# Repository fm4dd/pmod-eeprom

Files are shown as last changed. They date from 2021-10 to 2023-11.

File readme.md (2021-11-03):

## PMOD-EEPROM



### Description

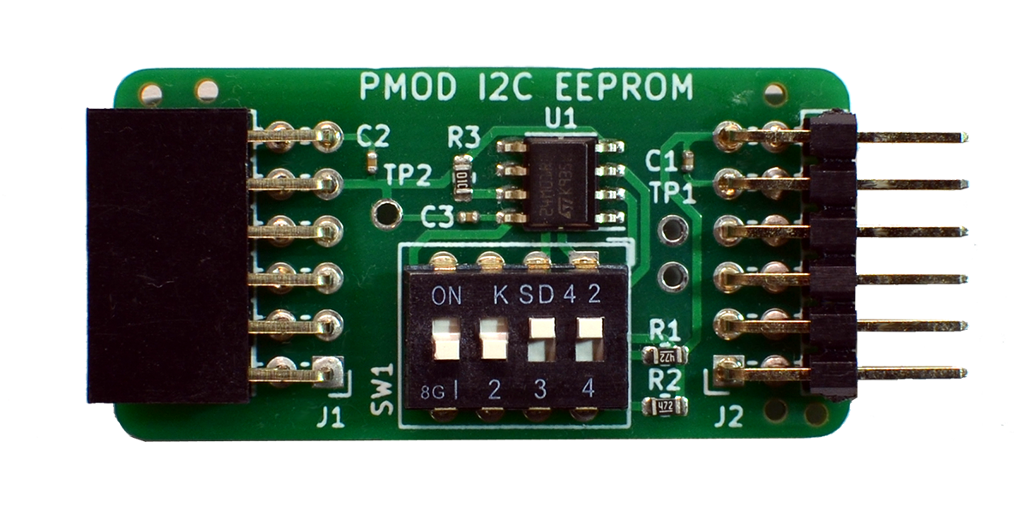
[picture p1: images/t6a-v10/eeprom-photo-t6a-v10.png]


This I2C PMOD provides a 1 Mbit serial EEPROM, using the M24M01 circuit by STMicroelectronics. DIP switches enable I2C pull-up resistors if needed, and change the EEPROM's I2C device address. Up to four modules can be chained for a total capacity of 4 Mbit (512 KBytes). Three Testpoints can be fitted for I2C bus troubleshooting. The PMOD has designs for Type-6 (I2C single row), and for the new Type-6A (I2C extended double row). The picture shows the Type-6A variant (engineering sample).

http://fpga.fm4dd.com/

### Schematic
This is the schema for the PMOD I2C Type-6 (single row) connector variant:
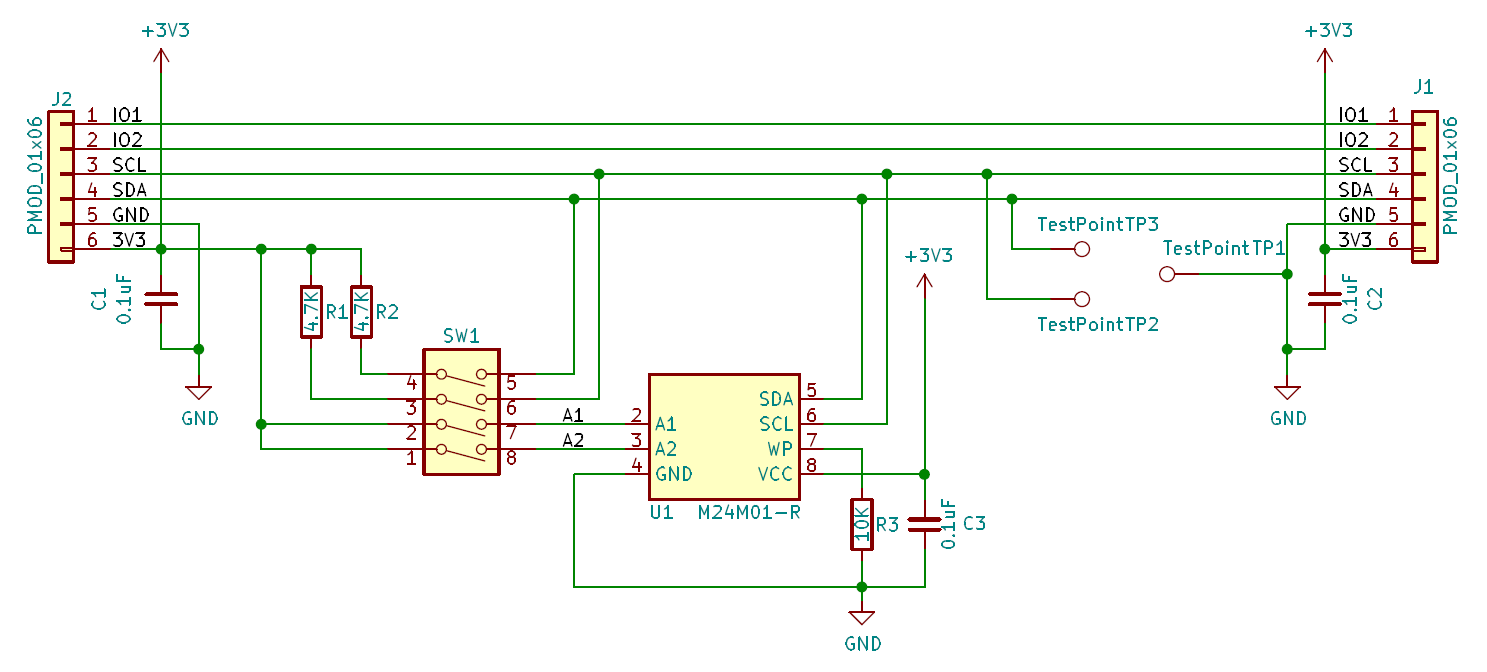
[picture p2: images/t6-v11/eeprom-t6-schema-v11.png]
EEPROM PMOD Schematics


The current EEPROM desin is pulling the "write-protect" pin high for "read-write" operation. A design update may implement a solder pad for setting the EEPROM 'read-only' after programming.

### Hardware Release

|Type | Version | Gerber | Schema |
|---|---|---|---|
|Type-6 |1.1 |[EEPROM PMOD Type-6 Gerber V1.1](release/t6-v11/20210917-eeprom-t6-gerber-v11.zip) | [20210917-eeprom-t6-schema-v11.pdf](release/t6-v11/20210917-eeprom-t6-schema-v11.pdf)
|Type-6A  |1.1 |[EEPROM PMOD Type-6A Gerber V1.1](release/t6a-v11/20210814-eeprom-t6a-gerber-v11.zip) | [20210814-eeprom-t6a-schema-v11.pdff](release/t6a-v11/20210814-eeprom-t6a-schema-v11.pdf)

#### Rasperry Pi I2C Discovery

Ensure the I2C bus is enabled, and install prerequisite I2C tools:
```
# sudo apt-get install git i2c-tools
# raspi-config  2 Interface Options  enable I2C
```

Check the IO expander circuit is visible on the I2C bus under address 0x50..0x56, depending on the address set through the DIP switch. Below example address 0x50/51 is set with SW1-1 = off and SW1-2 = off.
```
pi@pi-ms05:~ $ i2cdetect -y 1
     0  1  2  3  4  5  6  7  8  9  a  b  c  d  e  f
00:          -- -- -- -- -- -- -- -- -- -- -- -- --
10: -- -- -- -- -- -- -- -- -- -- -- -- -- -- -- --
20: -- -- -- -- -- -- -- -- -- -- -- -- -- -- -- --
30: -- -- -- -- -- -- -- -- -- -- -- -- -- -- -- --
40: -- -- -- -- -- -- -- -- -- -- -- -- -- -- -- --
50: 50 51 -- -- -- -- -- -- -- -- -- -- -- -- -- --
60: -- -- -- -- -- -- -- -- -- -- -- -- -- -- -- --
70: -- -- -- -- -- -- -- --
```

### Example code

pmod-eeprom code examples for Arduino boards are available in the [example folder](examples/)

On the Raspberry Pi, the PMOD can be easily programmed with the eeprom utility program 'eepflash.sh'. This program writes a manually created byte file (.eep) as content into the I2C eeprom. It can be found as part of the Raspberry Pi foundation 'hats' repository:
```
pi@pi-ms05:~ $ git clone https://github.com/raspberrypi/hats.git
Cloning into 'hats'...
remote: Enumerating objects: 565, done.
remote: Counting objects: 100% (95/95), done.
remote: Compressing objects: 100% (61/61), done.
remote: Total 565 (delta 59), reused 46 (delta 34), pack-reused 470
Receiving objects: 100% (565/565), 306.34 KiB | 936.00 KiB/s, done.
Resolving deltas: 100% (325/325), done.
```

Compile the tools located in the eepromutils subdirectory:
```
pi@pi-ms05:~ $ cd hats/eepromutils/
pi@pi-ms05:~/hats/eepromutils $ make clean; make
rm -f eepmake eepdump
cc -Wall -Wextra eepmake.c -o eepmake
cc -Wall -Wextra eepdump.c -o eepdump
```
Check the tools:
```
pi@pi-ms05:~/hats/eepromutils $ ls -l
total 84
-rwxr-xr-x 1 pi pi 12820 Aug 28 22:38 eepdump
-rw-r--r-- 1 pi pi  8112 Aug 28 22:37 eepdump.c
-rwxr-xr-x 1 pi pi  3906 Aug 28 22:37 eepflash.sh
-rwxr-xr-x 1 pi pi 22232 Aug 28 22:38 eepmake
-rw-r--r-- 1 pi pi 15144 Aug 28 22:37 eepmake.c
-rwxr-xr-x 1 pi pi  3122 Aug 28 22:37 eeprom_settings.txt
-rw-r--r-- 1 pi pi  2395 Aug 28 22:37 eeptypes.h
-rw-r--r-- 1 pi pi   677 Aug 28 22:37 Makefile
-rw-r--r-- 1 pi pi  1836 Aug 28 22:37 README.md
```

Example upload of an .eep file:
```
pi@pi-ms05:~/hats/eepromutils $ sudo ./eepflash.sh -w -f=rpi2pmod.eep -t=24c32 -d=1 -a=50
This will attempt to talk to an eeprom at i2c address 0x50 on bus 1. Make sure there is an eeprom at this address.
This script comes with ABSOLUTELY no warranty. Continue only if you know what you are doing.
Do you wish to continue? (yes/no): yes
Writing...
0+1 records in
0+1 records out
113 bytes copied, 0.728222 s, 0.2 kB/s
Closing EEPROM Device.
Done.
```

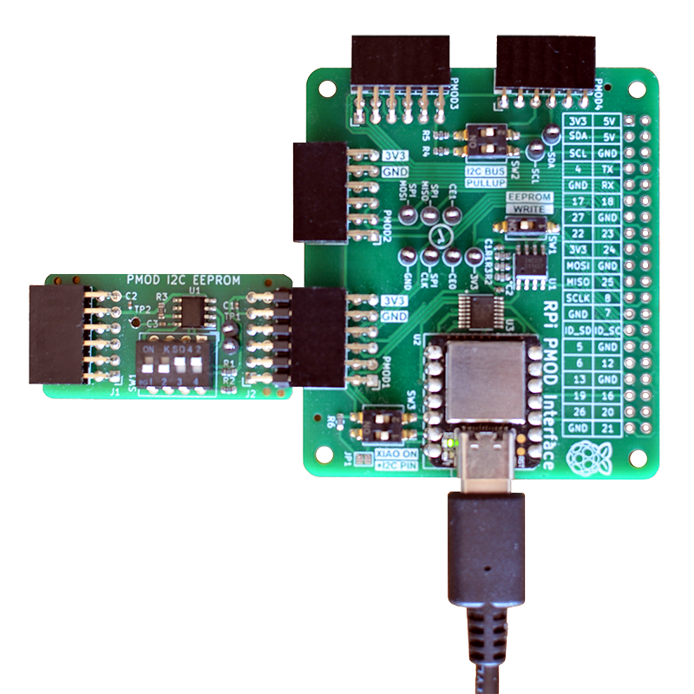
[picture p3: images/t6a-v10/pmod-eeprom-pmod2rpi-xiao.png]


PMOD-EEPROM on a PMOD2RPI interface board, running code from the XIAO Cortex M0+ MCU.

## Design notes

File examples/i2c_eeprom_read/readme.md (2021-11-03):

## i2c_eeprom_read

Arduino Sketch for designs based on the I2C EEPROM PMOD using the M24M01 circuit by STMicroelectronics. Implemented and tested on a PMOD2RPI interface board with a Seeeduino XIAO (Cortex M0+) and a PMOD-EEPROM module. 

### Usage

Running the sketch will output the following to the serial monitor:

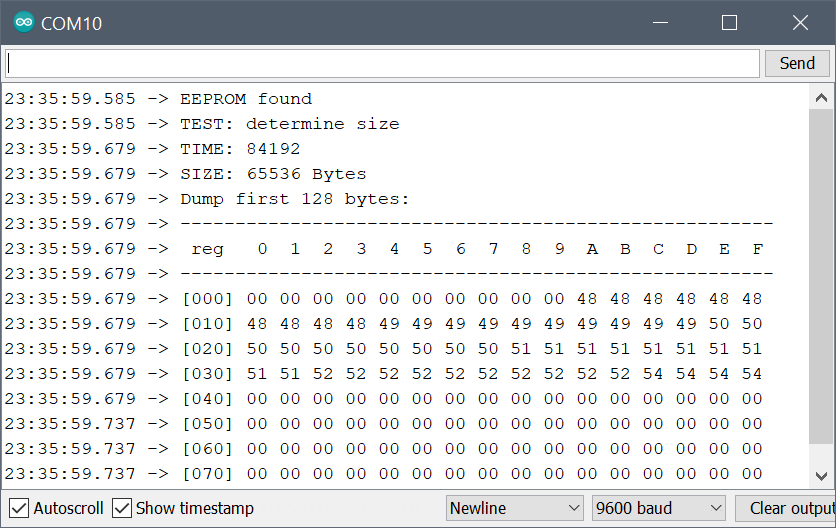
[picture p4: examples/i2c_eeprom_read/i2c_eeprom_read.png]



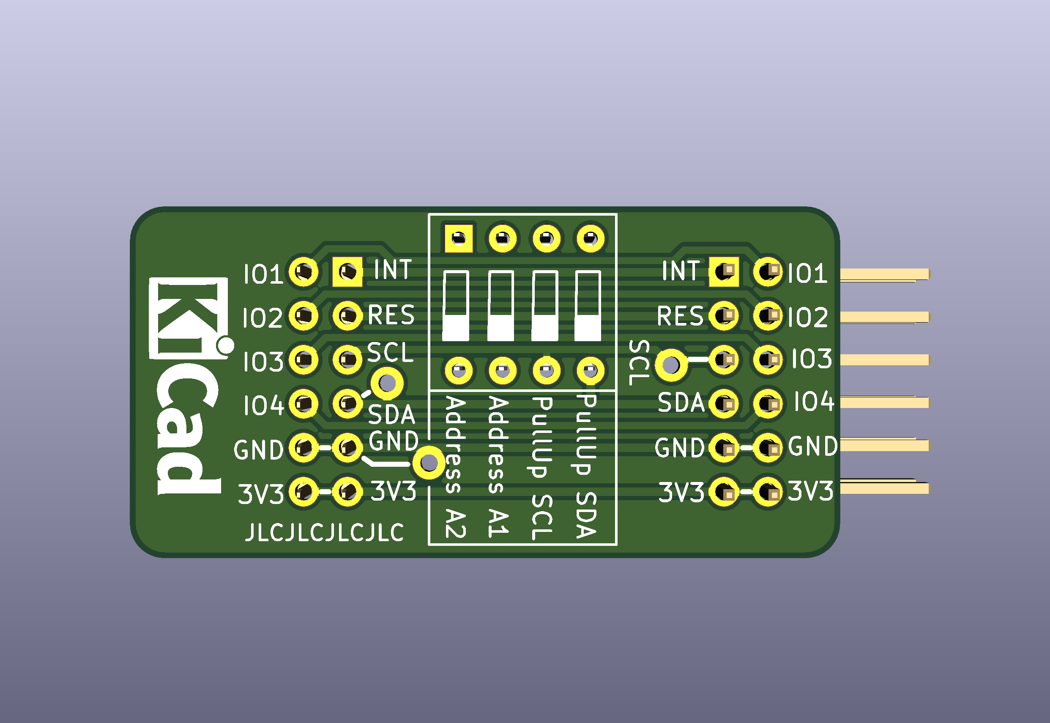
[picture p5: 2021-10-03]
images/t6a-v11/eeprom-bottom-t6a-v11.png

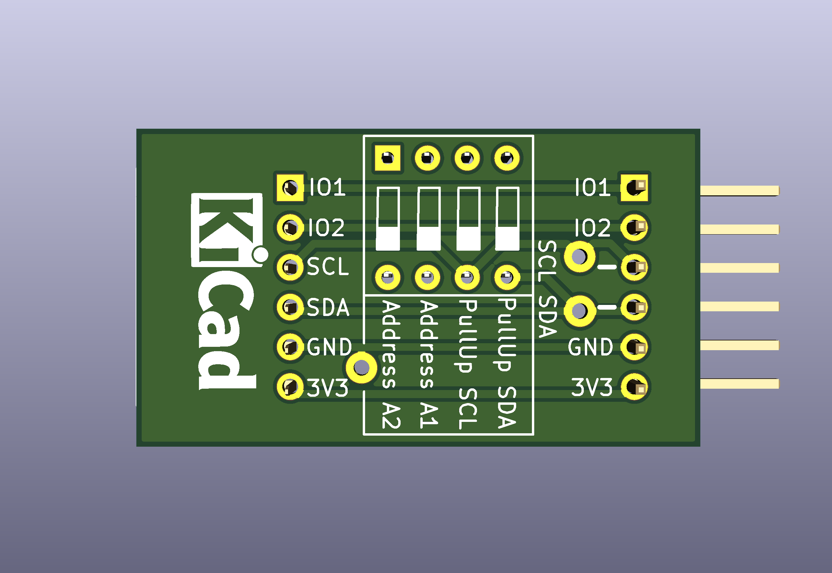
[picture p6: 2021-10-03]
images/t6-v11/eeprom-bottom-t6-v11.png

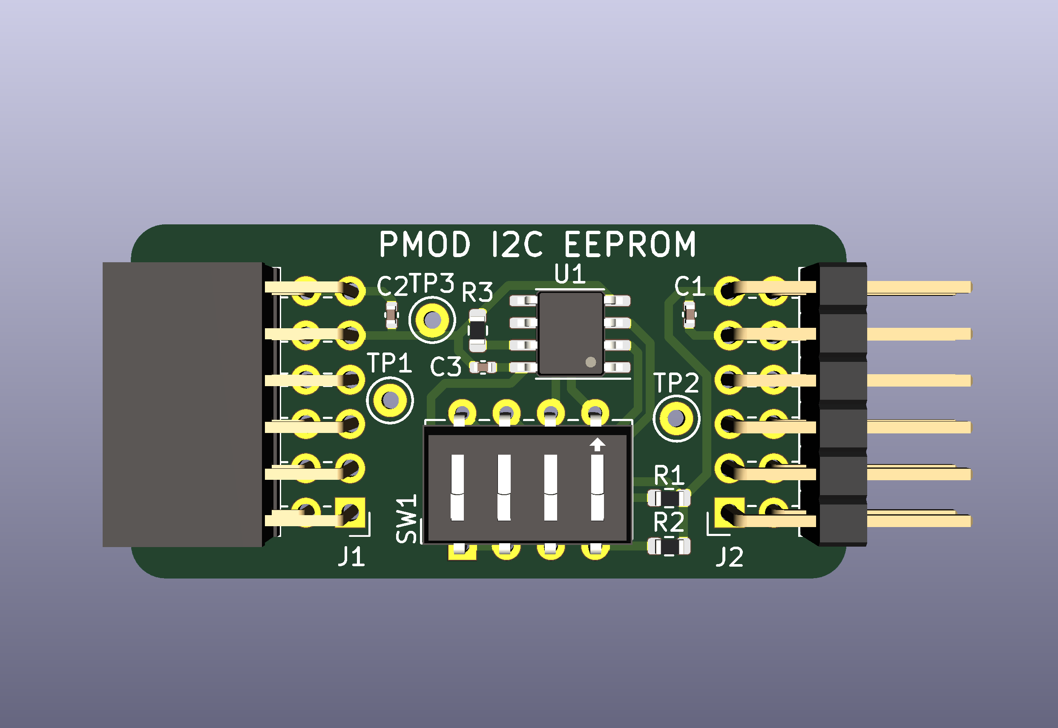
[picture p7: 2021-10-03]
images/t6a-v11/eeprom-top-t6a-v11.png

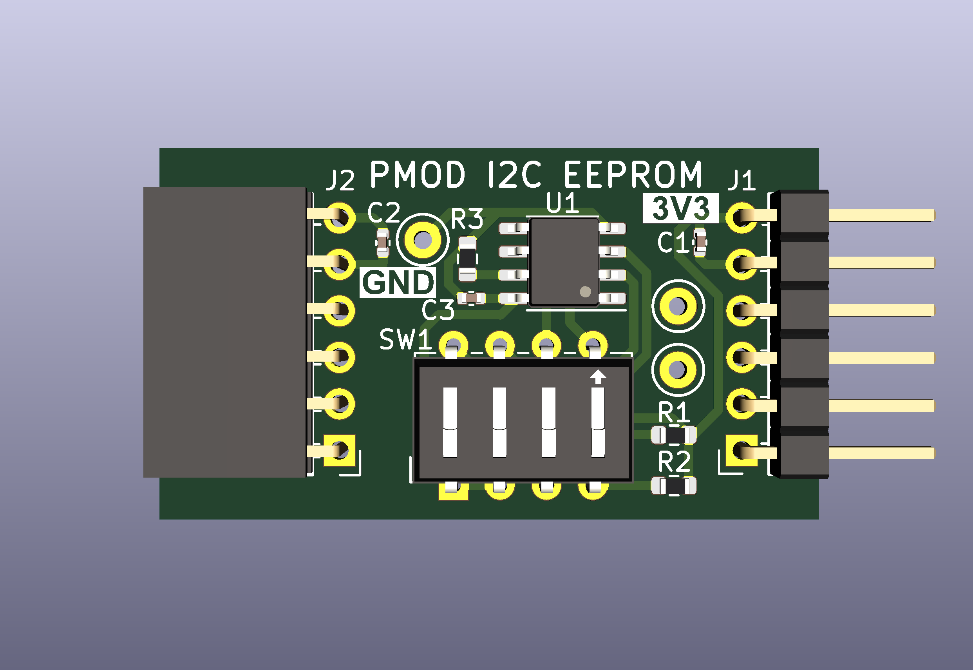
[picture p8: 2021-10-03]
images/t6-v11/eeprom-top-t6-v11.png

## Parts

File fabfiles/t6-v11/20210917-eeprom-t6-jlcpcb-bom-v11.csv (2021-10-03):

Comment | Designator | Footprint | LCSC Part #
M24M01-R | U1 | SOIC-8_3.9x4.9mm_P1.27mm
10K | R3 | Resistor_SMD:R_0603_1608Metric
4.7K | R2,R1 | Resistor_SMD:R_0603_1608Metric
0.1uF | C3,C2,C1 | Capacitor_SMD:C_0603_1608Metric

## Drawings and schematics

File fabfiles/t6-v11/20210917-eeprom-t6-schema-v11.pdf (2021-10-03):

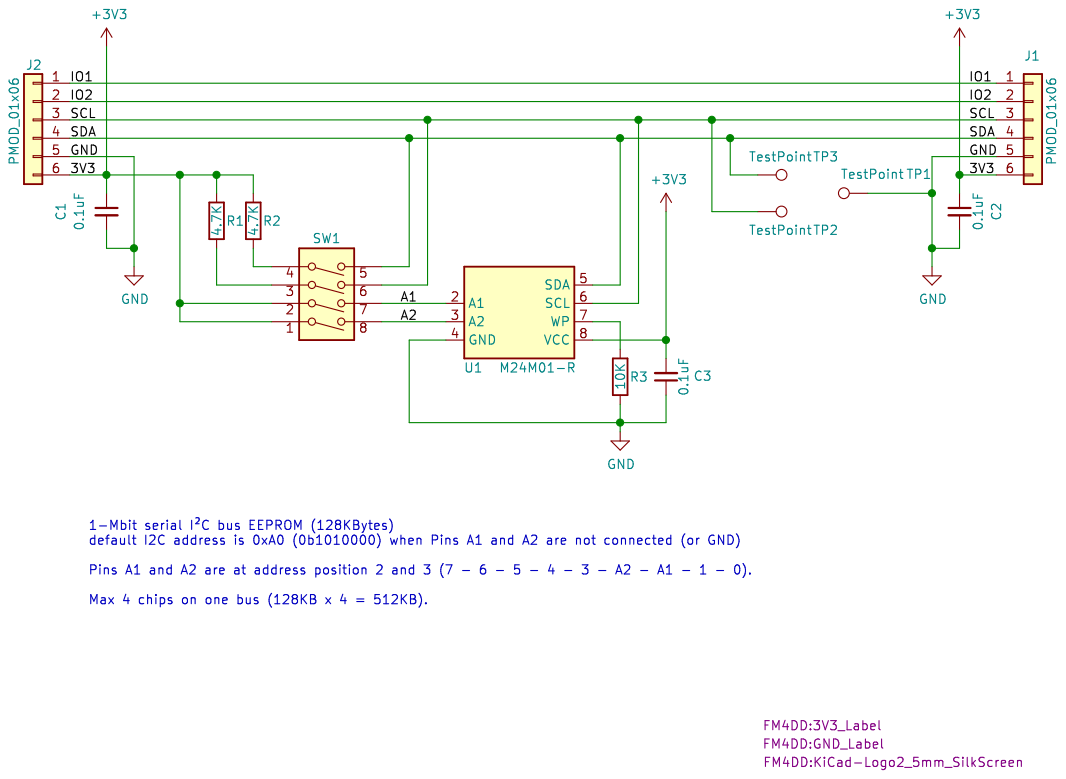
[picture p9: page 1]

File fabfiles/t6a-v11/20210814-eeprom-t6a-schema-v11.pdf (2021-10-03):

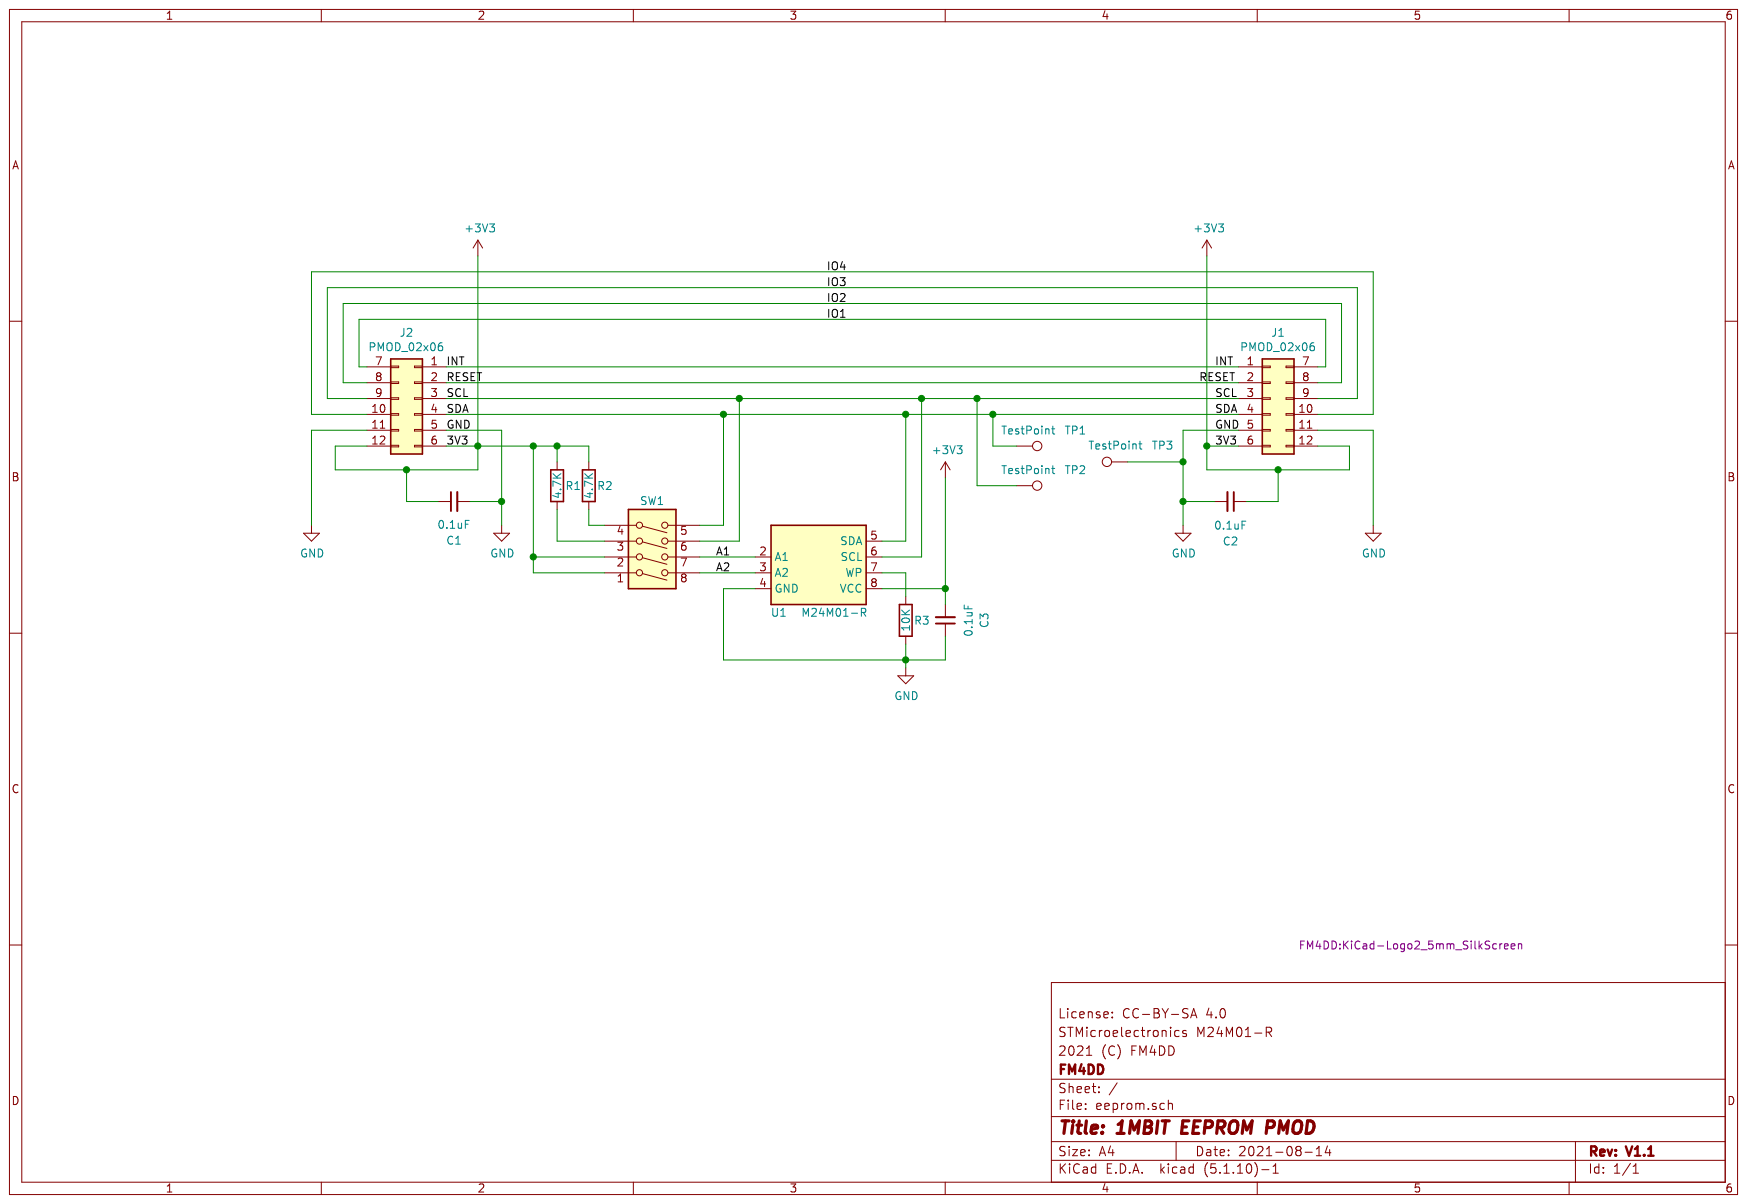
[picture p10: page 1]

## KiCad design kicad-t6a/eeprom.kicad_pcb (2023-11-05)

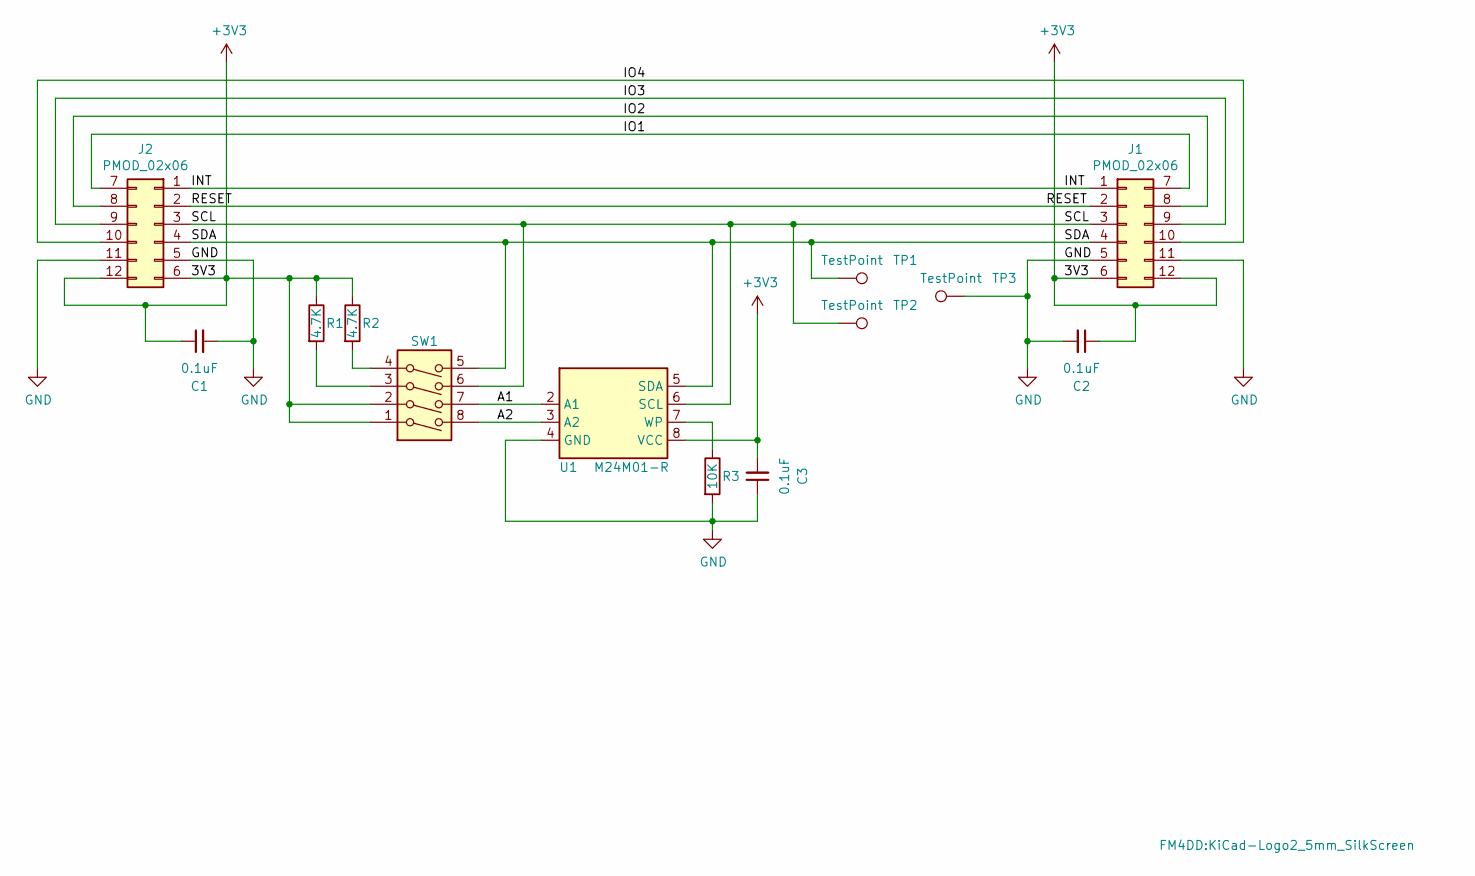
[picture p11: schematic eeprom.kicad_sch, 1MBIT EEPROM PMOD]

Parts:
C1, C2, C3: 0.1uF; C_0402_1005Metric
J1: PMOD_02x06; PMODPinSocket_2x06_P2.54mm_Horizontal
J2: PMOD_02x06; PMODHeader_2x06_P2.54mm_Horizontal
L1: Logo_KiCad_5mm; KiCad-Logo2_5mm_SilkScreen
R1, R2: 4.7K; R_0603_1608Metric
R3: 10K; R_0603_1608Metric
SW1: SW_DIP_x04; SW_DIP_SPSTx04_Slide_6.7x11.72mm_W7.62mm_P2.54mm_LowProfile
TP1, TP2, TP3: TestPoint; TestPoint_Keystone_5000-5004_Miniature
U1: M24M01-R; SOIC-8_3.9x4.9mm_P1.27mm

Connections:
+3V3: C1.1, C2.1, C3.2, J1.6, J1.12, J2.6, J2.12, R1.1, R2.1, SW1.1, SW1.2, U1.8 (VCC)
/A1: SW1.7, U1.2 (A1)
/A2: SW1.8, U1.3 (A2)
/INT: J1.1, J2.1
/IO1: J1.7, J2.7
/IO2: J1.8, J2.8
/IO3: J1.9, J2.9
/IO4: J1.10, J2.10
/RESET: J1.2, J2.2
/SCL: J1.3, J2.3, SW1.6, TP2.1, U1.6 (SCL)
/SDA: J1.4, J2.4, SW1.5, TP1.1, U1.5 (SDA)
GND: C1.2, C2.2, C3.1, J1.5, J1.11, J2.5, J2.11, R3.2, TP3.1, U1.4 (GND)
unnamed: R1.2, SW1.3
unnamed: R2.2, SW1.4
unnamed: R3.1, U1.7 (WP)

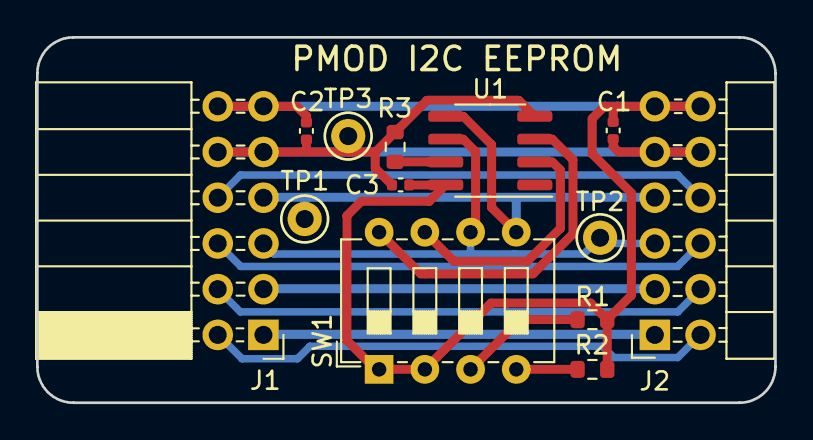
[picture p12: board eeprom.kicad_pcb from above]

Board: 2 copper layers, 41.0 x 20.3 mm, 15 parts (1 on the bottom side), 15 nets.

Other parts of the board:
Ref**: JLCPCB_Order_Number_Placeholder

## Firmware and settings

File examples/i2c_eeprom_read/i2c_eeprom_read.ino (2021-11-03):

/*
 * I2C EEPROM Read
 *
 * Reads the value of each byte of the I2C EEPROM and prints it
 * to the computer.
 * This example code is in the public domain.
 */

#include "Wire.h"
#include "I2C_eeprom.h"

#define i2c_address 0x50

// start reading from the first byte (address 0) of the EEPROM
int address = 0;
byte value;
uint32_t start, diff, totals = 0;

// Initialize using i2c_address, and eeprom size.  
I2C_eeprom ee(0x50, I2C_DEVICESIZE_24LC512);

void setup() {
  // initialize serial and wait for port to open:
  
  Serial.begin(9600);
  while (!Serial) {
    ; // wait for serial port to connect. Needed for native USB port only
  }
  ee.begin();
  if (! ee.isConnected()) {
    Serial.println("ERROR: Can't find eeprom\nstopped...");
    while (1);
  }
  Serial.println("EEPROM found");
  Serial.println("TEST: determine size");
  start = micros();
  uint32_t size = ee.determineSize();
  diff = micros() - start;
  Serial.print("TIME: ");
  Serial.println(diff);
  if (size > 0) {
    Serial.print("SIZE: ");
    Serial.print(size);
    Serial.println(" Bytes");
  } else if (size == 0) {
    Serial.println("WARNING: Can't determine eeprom size");
  }
  else {
    Serial.println("ERROR: Can't find eeprom\nstopped...");
    while (1);
  }
   Serial.println("Dump first 128 bytes:");
  dumpEEPROM(0, 128);
}

void loop() {
}

void dumpEEPROM(uint16_t memoryAddress, uint16_t length) {
  const int BLOCK_TO_LENGTH = 16;
  Serial.println("------------------------------------------------------"); 
  Serial.print(" reg   ");
  for (int x = 0; x < 16; x++)
  {
    if (x != 0) Serial.print("  ");
    Serial.print(x,HEX);
  }
  Serial.println();
  Serial.println("------------------------------------------------------"); 

  // block to defined length
  memoryAddress = memoryAddress / BLOCK_TO_LENGTH * BLOCK_TO_LENGTH;
  length = (length + BLOCK_TO_LENGTH - 1) / BLOCK_TO_LENGTH * BLOCK_TO_LENGTH;

  byte b = ee.readByte(memoryAddress);
  for (unsigned int i = 0; i < length; i++){
    char buf[6];
    if (memoryAddress % BLOCK_TO_LENGTH == 0){
      if (i != 0) Serial.println();
      sprintf(buf, "[%03x] ", memoryAddress);
      Serial.print(buf);
    }
    sprintf(buf, "%02d", b);
    Serial.print(buf);
    b = ee.readByte(++memoryAddress);
    Serial.print(" ");
  }
  Serial.println();
}

// END OF FILE

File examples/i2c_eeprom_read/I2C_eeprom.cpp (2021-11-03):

//
//    FILE: I2C_eeprom.cpp
//  AUTHOR: Rob Tillaart
// VERSION: 1.5.0
// PURPOSE: Arduino Library for external I2C EEPROM 24LC256 et al.
//     URL: https://github.com/RobTillaart/I2C_EEPROM.git
//
//  HISTORY:
//  0.1.00  2011-01-21  initial version
//  0.1.01  2011-02-07  added setBlock function
//  0.2.00  2011-02-11  fixed 64 bit boundary bug
//  0.2.01  2011-08-13  _readBlock made more robust + return value
//  1.0.00  2013-06-09  support for Arduino 1.0.x
//  1.0.01  2013-11-01  fixed writeBlock bug, refactor
//  1.0.02  2013-11-03  optimize internal buffers, refactor
//  1.0.03  2013-11-03  refactor 5 millis() write-latency
//  1.0.04  2013-11-03  fix bug in readBlock, moved waitEEReady()
//                      -> more efficient.
//  1.0.05  2013-11-06  improved waitEEReady(),
//                      added determineSize()
//  1.1.00  2013-11-13  added begin() function (Note breaking interface)
//                      use faster block Wire.write()
//                      int casting removed
//  1.2.00  2014-05-21  Added support for Arduino DUE ( thanks to Tyler F.)
//  1.2.01  2014-05-21  Refactoring
//  1.2.02  2015-03-06  stricter interface
//  1.2.03  2015-05-15  bugfix in _pageBlock & example (thanks ifreislich )
//  1.2.4   2017-04-19  remove timeout - issue #63
//  1.2.5   2017-04-20  refactor the removed timeout (Thanks to Koepel)
//  1.2.6   2019-02-01  fix issue #121
//  1.2.7   2019-09-03  fix issue #113 and #128
//  1.3.0   2020-06-19  refactor; removed pre 1.0 support; added ESP32 support.
//  1.3.1   2020-12-22  Arduino-CI + unit tests + updateByte()
//  1.3.2   2021-01-18  cyclic store functionality (Thanks to Tomas Hübner)
//  1.4.0   2021-01-27  rewritten addressing scheme + determineSize
//                      See determineSize for all tested.
//  1.4.1   2021-01-28  fixed addressing bug 24LC04/08/16 equivalents from ST e.g. m24c08w
//                      add Wire1..WireN;
//  1.4.2   2021-01-31  add updateBlock()
//  1.4.3   2021-05-05  adjust buffer size AVR / ESP +rename
//  1.5.0   2021-06-30  #28 fix addressing 24LC04/08/16
 

#include "I2C_eeprom.h"

// Not used directly
#define I2C_PAGESIZE_24LC512          128
#define I2C_PAGESIZE_24LC256           64
#define I2C_PAGESIZE_24LC128           64
#define I2C_PAGESIZE_24LC64            32
#define I2C_PAGESIZE_24LC32            32
#define I2C_PAGESIZE_24LC16            16
#define I2C_PAGESIZE_24LC08            16
#define I2C_PAGESIZE_24LC04            16
#define I2C_PAGESIZE_24LC02             8
#define I2C_PAGESIZE_24LC01             8


//  I2C buffer needs max 2 bytes for EEPROM address
//  1 byte for EEPROM register address is available in transmit buffer
#if defined(ESP32) || defined(ESP8266)
#define I2C_BUFFERSIZE           128
#else
#define I2C_BUFFERSIZE           30   //  AVR, STM 
#endif


I2C_eeprom::I2C_eeprom(const uint8_t deviceAddress, TwoWire *wire)
{
    I2C_eeprom(deviceAddress, I2C_PAGESIZE_24LC256, wire);
}


I2C_eeprom::I2C_eeprom(const uint8_t deviceAddress, const uint32_t deviceSize, TwoWire *wire)
{
    _deviceAddress = deviceAddress;
    _deviceSize = deviceSize;
    _pageSize = getPageSize(_deviceSize);
    _wire = wire;

    // Chips 16Kbit (2048 Bytes) or smaller only have one-word addresses.
    this->_isAddressSizeTwoWords = deviceSize > I2C_DEVICESIZE_24LC16;
}


#if defined (ESP8266) || defined(ESP32)
bool I2C_eeprom::begin(uint8_t sda, uint8_t scl)
{
  if ((sda < 255) && (scl < 255))
  {
    _wire->begin(sda, scl);
  }
  else
  {
    _wire->begin();
  }
  _lastWrite = 0;
  return isConnected();
}
#endif


bool I2C_eeprom::begin()
{
  _wire->begin();
  _lastWrite = 0;
  return isConnected();
}


bool I2C_eeprom::isConnected()
{
  _wire->beginTransmission(_deviceAddress);
  return (_wire->endTransmission() == 0);
}


int I2C_eeprom::writeByte(const uint16_t memoryAddress, const uint8_t data)
{
  int rv = _WriteBlock(memoryAddress, &data, 1);
  return rv;
}


int I2C_eeprom::setBlock(const uint16_t memoryAddress, const uint8_t data, const uint16_t length)
{
  uint8_t buffer[I2C_BUFFERSIZE];
  for (uint8_t i = 0; i < I2C_BUFFERSIZE; i++)
  {
    buffer[i] = data;
  }
  int rv = _pageBlock(memoryAddress, buffer, length, false);
  return rv;
}


int I2C_eeprom::writeBlock(const uint16_t memoryAddress, const uint8_t* buffer, const uint16_t length)
{
  int rv = _pageBlock(memoryAddress, buffer, length, true);
  return rv;
}


uint8_t I2C_eeprom::readByte(const uint16_t memoryAddress)
{
  uint8_t rdata;
  _ReadBlock(memoryAddress, &rdata, 1);
  return rdata;
}


uint16_t I2C_eeprom::readBlock(const uint16_t memoryAddress, uint8_t* buffer, const uint16_t length)
{
  uint16_t addr = memoryAddress;
  uint16_t len = length;
  uint16_t rv = 0;
  while (len > 0)
  {
    uint8_t cnt = I2C_BUFFERSIZE;
    if (cnt > len) cnt = len;
    rv     += _ReadBlock(addr, buffer, cnt);
    addr   += cnt;
    buffer += cnt;
    len    -= cnt;
    yield();    // For OS scheduling
  }
  return rv;
}


int I2C_eeprom::updateByte(const uint16_t memoryAddress, const uint8_t data)
{
  if (data == readByte(memoryAddress)) return 0;
  return writeByte(memoryAddress, data);
}

int I2C_eeprom::updateBlock(const uint16_t memoryAddress, const uint8_t* buffer, const uint16_t length)
{
  uint16_t addr = memoryAddress;
  uint16_t len = length;
  uint16_t rv = 0;
  while (len > 0)
  {
    uint8_t buf[I2C_BUFFERSIZE];
    uint8_t cnt = I2C_BUFFERSIZE;
    
    if (cnt > len) cnt = len;
    rv     += _ReadBlock(addr, buf, cnt);
    if (memcmp(buffer, buf, cnt) != 0)
    {
      _pageBlock(addr, buffer, cnt, true);
    }
    addr   += cnt;
    buffer += cnt;
    len    -= cnt;
    yield();    // For OS scheduling
  }
  return rv;
}
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

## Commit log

2021-10-03 initial check-in
    [20210814-eeprom-t6a-jlcpcb-bom-v11.csv, 20210917-eeprom-t6-jlcpcb-bom-v11.csv, eeprom.kicad_pcb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]
2023-11-05 KiCad v7 upgrade, manual workflow trigger
    [20210814-eeprom-t6a-jlcpcb-bom-v11.csv, 20210917-eeprom-t6-jlcpcb-bom-v11.csv, eeprom.kicad_pcb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]

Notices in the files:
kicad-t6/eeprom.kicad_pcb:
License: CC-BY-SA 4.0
